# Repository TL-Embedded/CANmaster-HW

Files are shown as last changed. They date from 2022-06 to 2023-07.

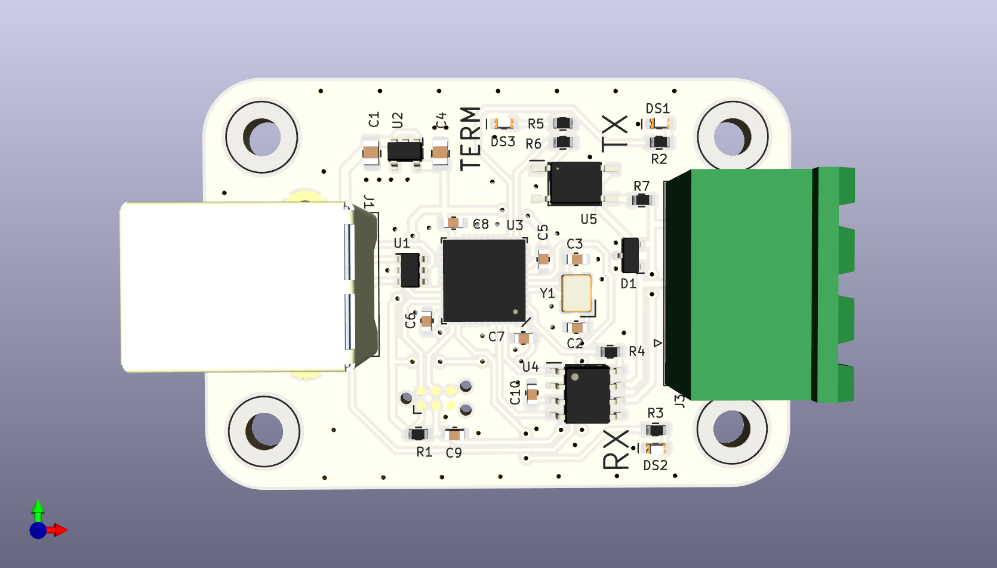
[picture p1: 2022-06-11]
Canmaster_HW.png

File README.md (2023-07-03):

# CANmaster-HW

This is the hardware for the CANMaster USB to CAN adaptor.

See [CANmaster-FW](https://github.com/TL-Embedded/CANmaster-FW) for programming instructions and behavior description.

Hardware is done via KiCad. The processor is a STM32F072.

# USB
The STM32's native USB is used.

# CAN
The can interface is provided by either a `MCP2551-I/SN` or a `MAX33011EASA+`.
The MAX330 has better input protection, and reports error codes. The presense of the MAX330 shall be indicated by fitting 0R on R8.

The bus terminator is enabled in software via optoisolator.

The CAN bus is exposed via phoenix connector:

| Pin | Function |
| --- | --- |
| 1 | CANL |
| 2 | CANH |
| 3 | GND |

# Programming
Programming is done via a 6 pin TC2030 SWD interface.

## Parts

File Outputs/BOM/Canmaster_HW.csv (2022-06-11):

Id | Designator | Package | Quantity | Designation | Supplier and ref
1 | U4 | SOIC_8 | 1 | MCP2551-I/SN
2 | J1 | USB_B_TH_Horizontal | 1 | UJ2-BH-TH
3 | C8,C6,C7,C10,C5,C9 | C_0603 | 6 | 100n,50v
4 | U3 | QFN48_05_7x7_EP | 1 | STM32F072CxUx
5 | M1,M4,M2,M3 | Mount_M3 | 4 | Mount_M3
6 | U2 | SOT23_5 | 1 | NCP115ASN330T2G
7 | R5,R6,R2 | R_0603 | 3 | 300R
8 | J2 | TagConnect_2030_NL | 1 | TC_2030_NL_STLINK
9 | R9,R4 | R_0603 | 2 | 0R
10 | C2,C3 | C_0603 | 2 | 4.7p,50v
11 | DS1 | DS_0603 | 1 | LED,RED
12 | U1 | SOT23_6 | 1 | USBLC6-4SC6
13 | R1,R8 | R_0603 | 2 | 10K
14 | Y1 | Crystal_SMD4_3.2x2.5 | 1 | ECS-80-12-33-JGN-TR
15 | R7 | R_0603 | 1 | 120R
16 | J3 | PhoenixContact_MSTBA_2,5_3-G-5,08_1x03_P5.08mm_Horizontal | 1 | Conn_01x03
17 | DS3 | DS_0603 | 1 | LED,YEL
18 | R3 | R_0603 | 1 | 220R
19 | C4,C1 | C_0805 | 2 | 10u,16v
20 | D1 | SOT23_3 | 1 | D5V0L2B3SO-7
21 | U5 | SO4_2.54_4.4x3.6 | 1 | LTV-355T
22 | DS2 | DS_0603 | 1 | LED,GRN
23 | REF** | TL_Embedded | 1 | TL_Embedded

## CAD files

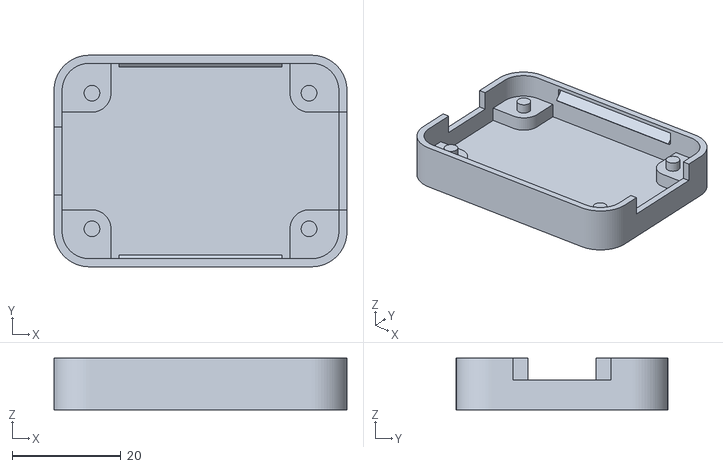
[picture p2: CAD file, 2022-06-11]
Enclosure/Canmaster_Case_Bot_v19.stl
54.0 x 39.0 x 9.50

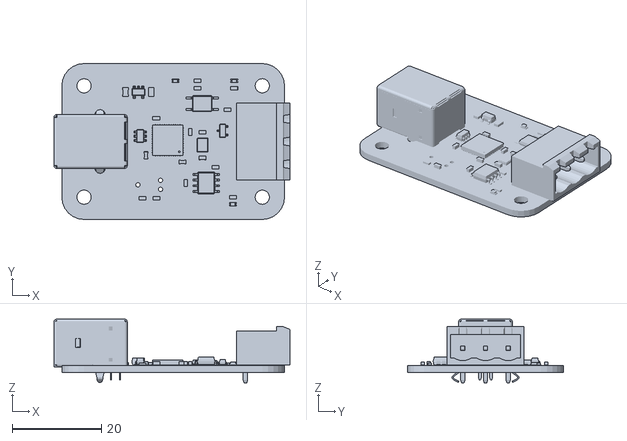
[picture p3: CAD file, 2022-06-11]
Enclosure/Canmaster_HW v1.obj
53.0 x 35.0 x 14.3

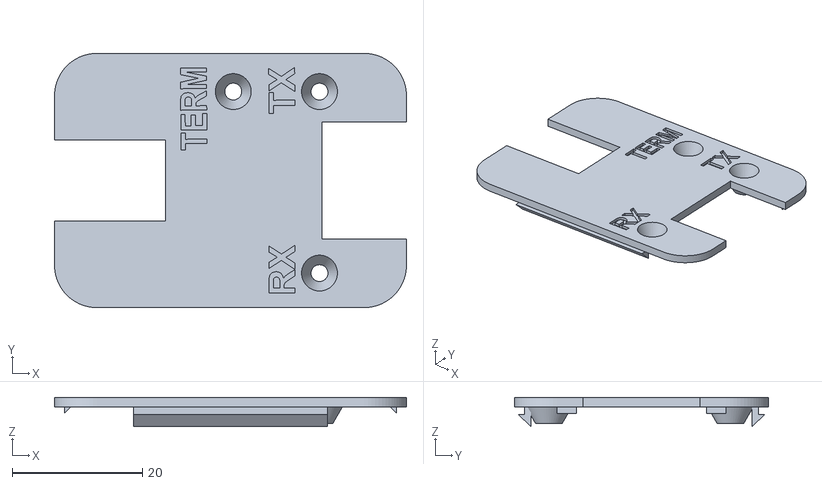
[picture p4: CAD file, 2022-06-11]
Enclosure/Canmaster_Case_Top_v14.stl
54.0 x 39.0 x 4.50

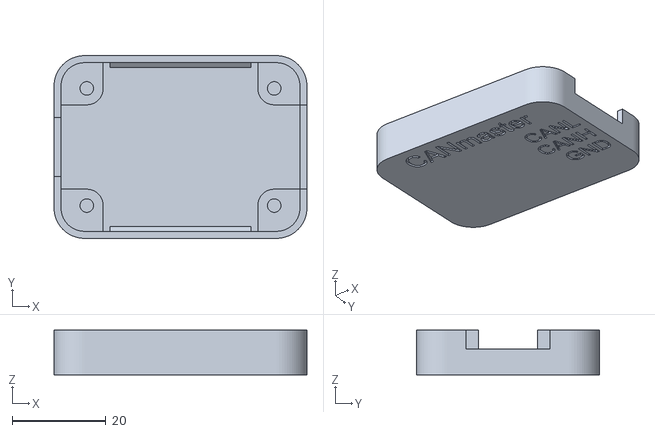
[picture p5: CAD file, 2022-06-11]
Enclosure/Canmaster_Case_ Bot_v10.stl
54.0 x 39.0 x 9.50

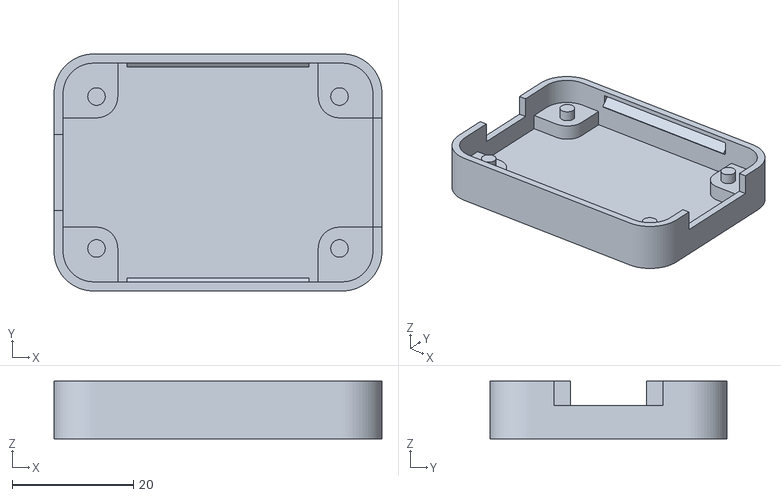
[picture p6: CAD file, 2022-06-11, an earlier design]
Enclosure/Canmaster_Case_Bot_v16.stl
54.0 x 39.0 x 9.50

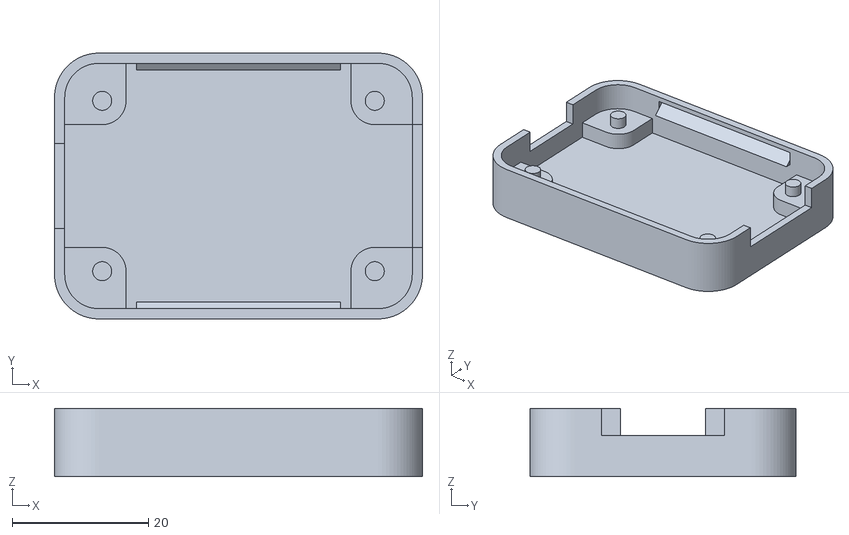
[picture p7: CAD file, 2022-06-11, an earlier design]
Enclosure/Canmaster_Case_Bot_v1.stl
54.0 x 39.0 x 10.0

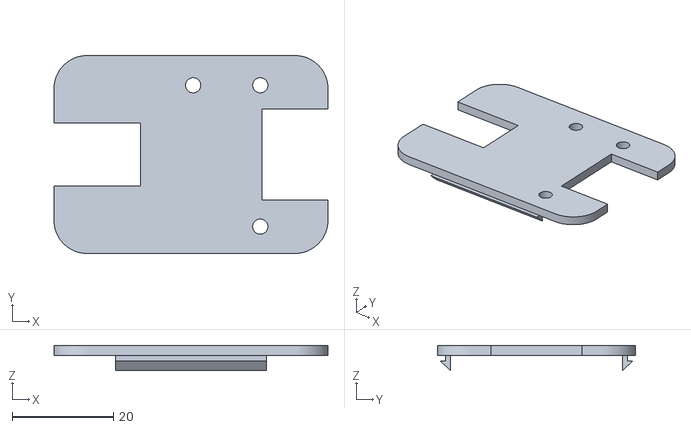
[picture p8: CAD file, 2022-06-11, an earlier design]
Enclosure/Canmaster_Case_Top_v1.stl
54.0 x 39.0 x 5.00

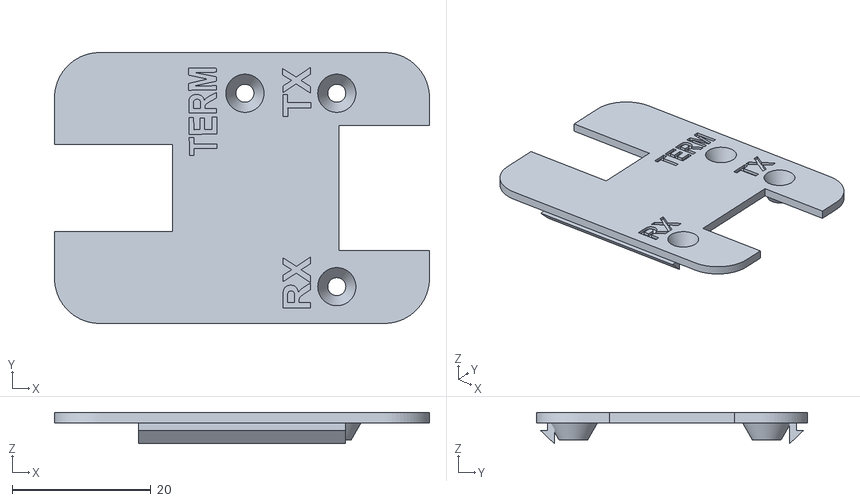
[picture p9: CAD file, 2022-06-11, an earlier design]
Enclosure/Canmaster_Case_Top_v10.stl
54.0 x 39.0 x 4.50

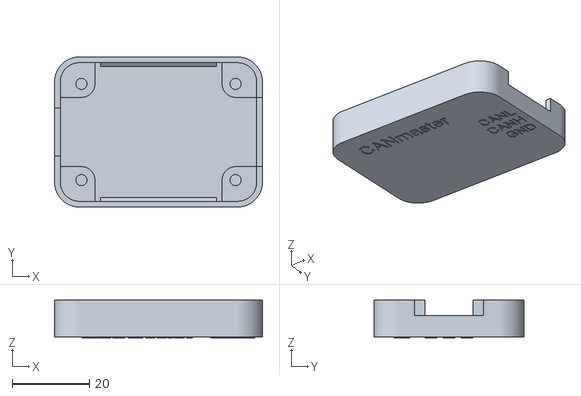
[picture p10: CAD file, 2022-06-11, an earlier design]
Enclosure/Canmaster_Case_Bot_v6.stl
54.0 x 39.0 x 9.75

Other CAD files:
Enclosure/Canmaster_Case_Bot_v18.stl
Enclosure/Canmaster_Case_Bot_v14.stl
Enclosure/Canmaster_Case_Top_v6.stl

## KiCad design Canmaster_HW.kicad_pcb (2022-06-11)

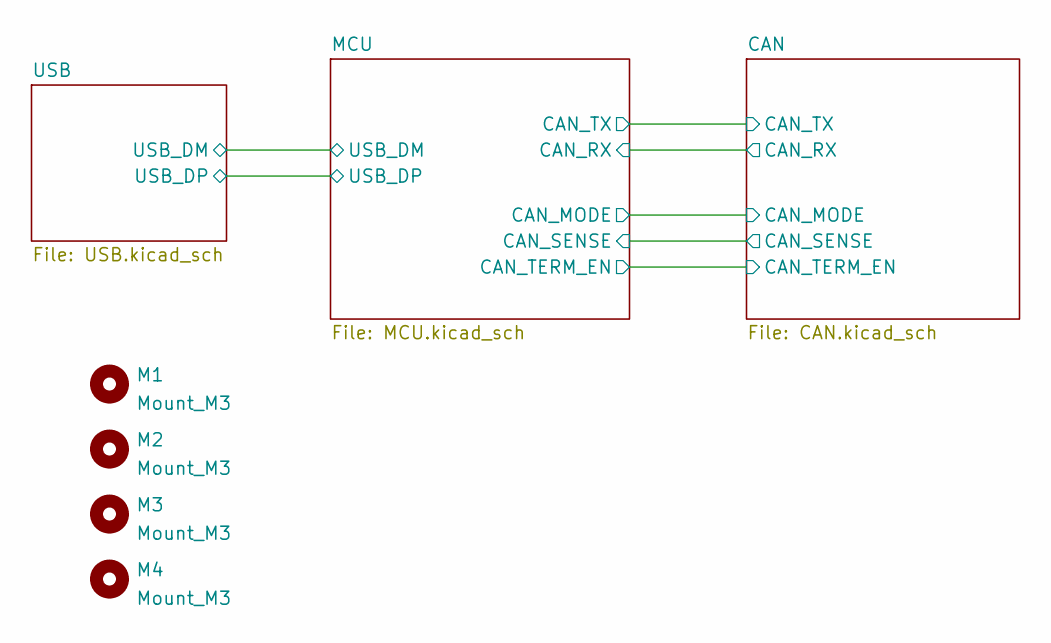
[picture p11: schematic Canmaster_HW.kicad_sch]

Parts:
M1, M2, M3, M4: Mount_M3

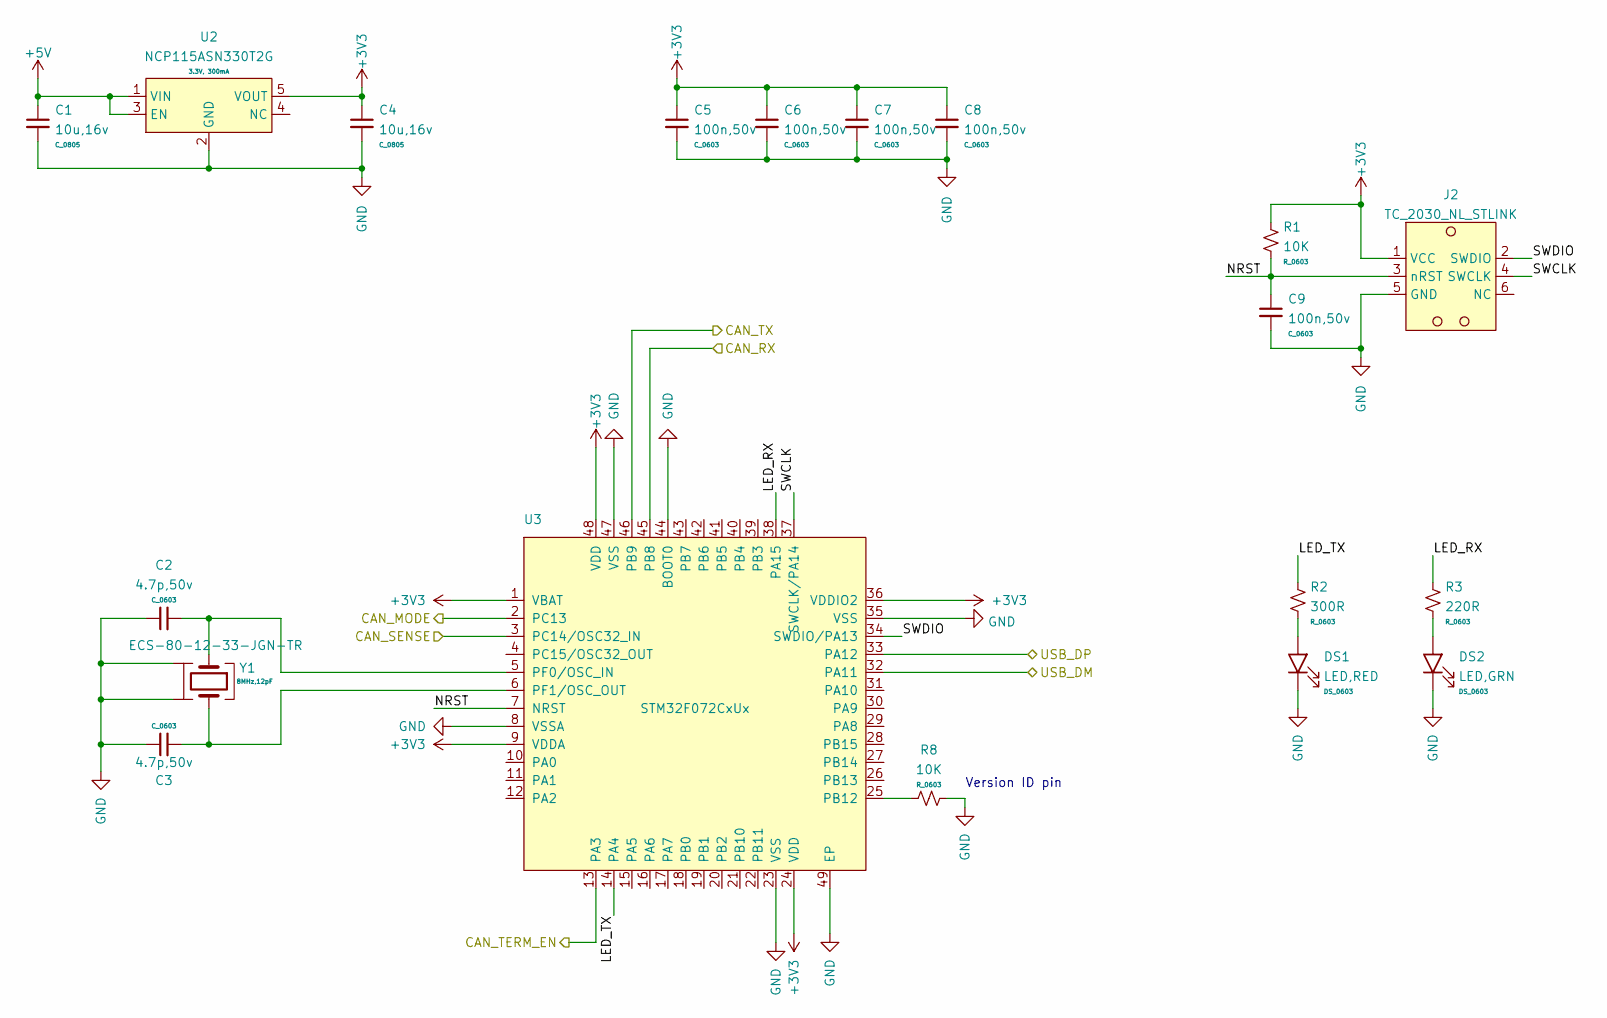
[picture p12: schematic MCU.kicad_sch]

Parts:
C1, C4: 10u,16v; C_0805
C2, C3: 4.7p,50v; C_0603
C5, C6, C7, C8, C9: 100n,50v; C_0603
DS1: LED,RED; DS_0603
DS2: LED,GRN; DS_0603
J2: TC_2030_NL_STLINK; TagConnect_2030_NL
R1, R8: 10K; R_0603
R2: 300R; R_0603
R3: 220R; R_0603
U2: NCP115ASN330T2G; SOT23_5
U3: STM32F072CxUx; QFN48_05_7x7_EP
Y1: ECS-80-12-33-JGN-TR; Crystal_SMD4_3.2x2.5

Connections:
+3V3: C4.1, C5.1, C6.1, C7.1, C8.1, J2.1 (VCC), R1.1, U2.5 (VOUT), U3.1 (VBAT), U3.9 (VDDA), U3.24 (VDD), U3.36 (VDDIO2), U3.48 (VDD)
+5V: C1.1, U2.1 (VIN), U2.3 (EN); also elsewhere on the board
/CAN/CAN_MODE: U3.2 (PC13); also elsewhere on the board
/CAN/CAN_RX: U3.45 (PB8); also elsewhere on the board
/CAN/CAN_SENSE: U3.3 (PC14/OSC32_IN); also elsewhere on the board
/CAN/CAN_TERM_EN: U3.13 (PA3); also elsewhere on the board
/CAN/CAN_TX: U3.46 (PB9); also elsewhere on the board
/MCU/LED_RX: R3.1, U3.38 (PA15)
/MCU/LED_TX: R2.1, U3.14 (PA4)
/MCU/NRST: C9.1, J2.3 (nRST), R1.2, U3.7 (NRST)
/MCU/SWCLK: J2.4 (SWCLK), U3.37 (SWCLK/PA14)
/MCU/SWDIO: J2.2 (SWDIO), U3.34 (SWDIO/PA13)
/MCU/USB_DM: U3.32 (PA11); also elsewhere on the board
/MCU/USB_DP: U3.33 (PA12); also elsewhere on the board
GND: C1.2, C2.1, C3.1, C4.2, C5.2, C6.2, C7.2, C8.2, C9.2, DS1.1 (K), DS2.1 (K), J2.5 (GND), R8.1, U2.2 (GND), U3.8 (VSSA), U3.23 (VSS), U3.35 (VSS), U3.44 (BOOT0), U3.47 (VSS), U3.49 (EP), Y1.2, Y1.4; also elsewhere on the board
unnamed: C2.2, U3.5 (PF0/OSC_IN), Y1.1
unnamed: C3.2, U3.6 (PF1/OSC_OUT), Y1.3
unnamed: DS1.2 (A), R2.2
unnamed: DS2.2 (A), R3.2
unnamed: R8.2, U3.25 (PB12)

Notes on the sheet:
Version ID pin

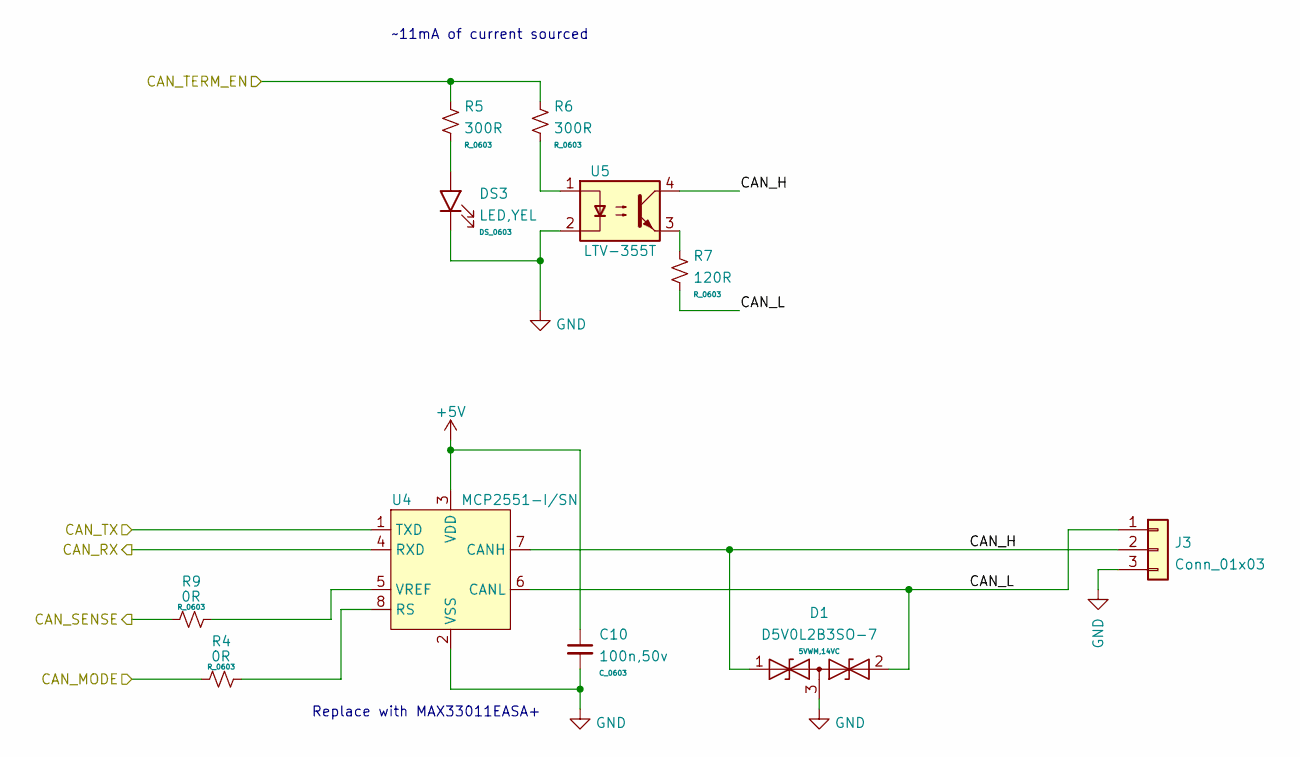
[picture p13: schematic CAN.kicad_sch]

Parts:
C10: 100n,50v; C_0603
D1: D5V0L2B3SO-7; SOT23_3
DS3: LED,YEL; DS_0603
J3: Conn_01x03; PhoenixContact_MSTBA_2,5_3-G-5,08_1x03_P5.08mm_Horizontal
R4, R9: 0R; R_0603
R5, R6: 300R; R_0603
R7: 120R; R_0603
U4: MCP2551-I/SN; SOIC_8
U5: LTV-355T; SO4_2.54_4.4x3.6

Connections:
+5V: C10.1, U4.3 (VDD); also elsewhere on the board
/CAN/CAN_H: D1.1 (A1), J3.2, U4.7 (CANH), U5.4
/CAN/CAN_L: D1.2 (A2), J3.1, R7.2, U4.6 (CANL)
/CAN/CAN_MODE: R4.1; also elsewhere on the board
/CAN/CAN_RX: U4.4 (RXD); also elsewhere on the board
/CAN/CAN_SENSE: R9.1; also elsewhere on the board
/CAN/CAN_TERM_EN: R5.1, R6.1; also elsewhere on the board
/CAN/CAN_TX: U4.1 (TXD); also elsewhere on the board
GND: C10.2, D1.3 (common), DS3.1 (K), J3.3, U4.2 (VSS), U5.2; also elsewhere on the board
unnamed: DS3.2 (A), R5.2
unnamed: R4.2, U4.8 (RS)
unnamed: R6.2, U5.1
unnamed: R7.1, U5.3
unnamed: R9.2, U4.5 (VREF)

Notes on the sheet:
~11mA of current sourced
Replace with MAX33011EASA+

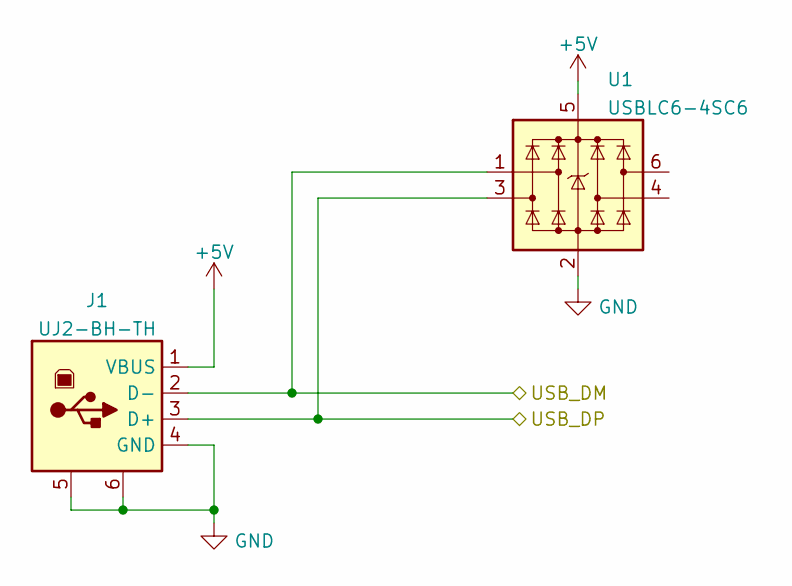
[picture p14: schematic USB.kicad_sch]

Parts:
J1: UJ2-BH-TH; USB_B_TH_Horizontal
U1: USBLC6-4SC6; SOT23_6

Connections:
+5V: J1.1 (VBUS), U1.5; also elsewhere on the board
/MCU/USB_DM: J1.2 (D-), U1.1; also elsewhere on the board
/MCU/USB_DP: J1.3 (D+), U1.3; also elsewhere on the board
GND: J1.4 (GND), J1.5, J1.6, U1.2; also elsewhere on the board

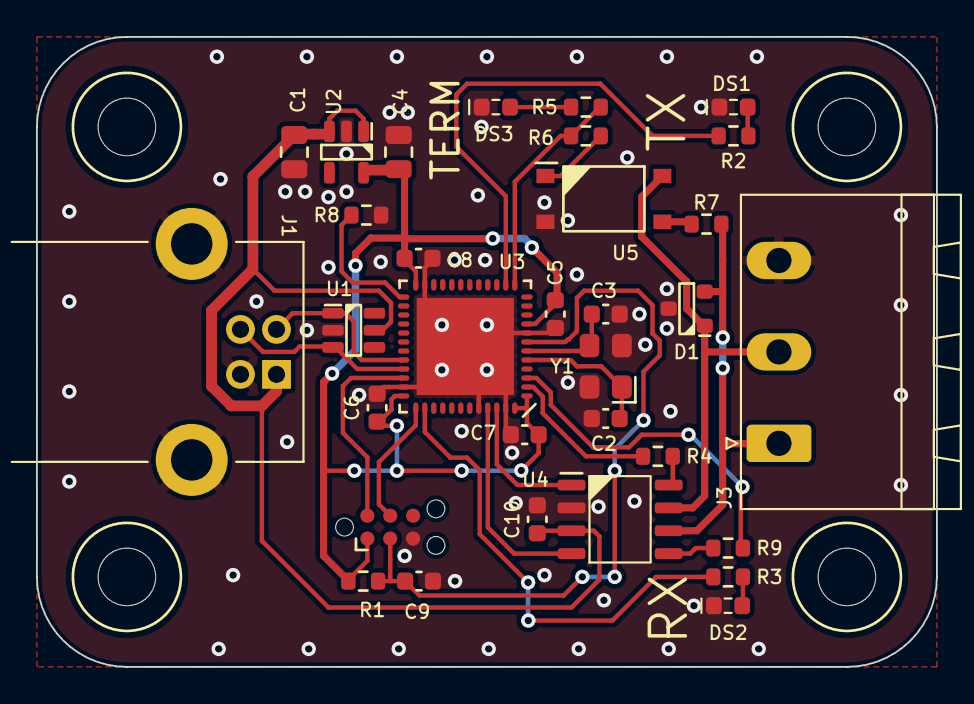
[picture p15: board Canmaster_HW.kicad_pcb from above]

Board: 2 copper layers, 50.0 x 35.0 mm, 36 parts (0 on the bottom side), 27 nets.

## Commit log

2022-04-24 Initial import
    [CAN.kicad_sch, Canmaster_HW.kicad_pcb, Canmaster_HW.kicad_sch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]
2022-04-24 Moved TX & RX LED's
    [Canmaster_HW.kicad_pcb]
2022-04-24 Fix BOOT0 pin being disconnected
    [Canmaster_HW.kicad_pcb, Canmaster_HW.kicad_sch, MCU.kicad_sch]
2022-05-29 Change RX LED to 220R
    [Canmaster_HW.kicad_sch, MCU.kicad_sch]
2022-06-11 Added connection for fault pin. Reversed CAN connector.
    Updated some footprints
    [CAN.kicad_sch, Canmaster_HW.kicad_pcb, Canmaster_HW.kicad_sch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]
2022-06-11 Correct LED colors
    [CAN.kicad_sch, Canmaster_HW.kicad_pcb, Canmaster_HW.kicad_sch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]
2022-06-11 Fix R3 & R9 label swap
    [Canmaster_HW.kicad_pcb]
2022-06-11 Rebuild pours
    [Canmaster_Case_ Bot_v10.stl, Canmaster_Case_Bot_v1.stl, Canmaster_Case_Bot_v14.stl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]
